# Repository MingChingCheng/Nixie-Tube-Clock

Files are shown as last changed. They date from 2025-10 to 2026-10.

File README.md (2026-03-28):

# Nixie-Tube-Clock

A project of Nixie tube clock.

## Hardware

- Powered by 12V DC charger

## Functions

- Clock with hour and minute
- Temperature
- Humidity
- Time setting mode
- de-poisoning the nixie tube every hour

## Library

List of the libraries used in this project:

- [Adafruit AM2320 sensor library](https://github.com/adafruit/Adafruit_AM2320) (by Adafruit)
- [DS3231](https://github.com/NorthernWidget/DS3231) (by Andrew Wickert)
- [RotaryEncoder](https://github.com/mathertel/RotaryEncoder) (by Matthias Hertel)

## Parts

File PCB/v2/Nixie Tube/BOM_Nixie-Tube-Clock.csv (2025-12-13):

ID | Name | Designator | Footprint | Quantity | Manufacturer Part | Manufacturer | Supplier | Supplier Part | Price | Contributor | link | 3DModel | JLCPCB Part Class | description
1 | 100nF | C1,C2 | C0603 | 2 | CC0603KRX7R9BB104 | YAGEO(国巨) | LCSC | C14663 |  | lcsc | https://item.szlcsc.com/362304.html | C0603_L1.6-W0.8-H0.8 | Basic Part
2 | NH-B2020RGBA-HF | LED1,LED2,LED3,LED4 | LED-ARRAY-SMD_4P-L2.1-W2.1-TL_NH-B2020RGBA | 4 | NH-B2020RGBA-HF | 国星光电 | LCSC | C2874116 |  | LCSC | https://atta.szlcsc.com/upload/public/pdf/source/20210810/F2CC95523506BC87574AF0308E7F77A3.pdf | LED-ARRAY-SMD_4P-L2.1-W2.1-TL_NH-B2020RGBA | Extended Part
3 | 10kΩ | R1,R2,R3,R4 | R2010 | 4 | RC2010FK-0710KL | YAGEO(国巨) | LCSC | C784591 |  | lcsc | https://lcsc.com/eda_search?q=C784591&%26type=1&ref=editor | R2010_L5.0-W2.5-H0.6 | Extended Part
4 | 74HC595 | U5,U6 | SOIC-16_L9.9-W3.9-P1.27-LS6.0-BL | 2 | 74HC595D,118 | Nexperia(安世) | LCSC | C5947 |  | lcsc | http://datasheet.octopart.com/MC14076BDR2G-ON-Semiconductor-datasheet-608107.pdf | SOIC-16_L9.9-W3.9-H1.8-LS6.0-P1.27 |  | 8-Bit Serial-InputSerial or Prallel-Output Shift Register with Latched 3-State Outputs

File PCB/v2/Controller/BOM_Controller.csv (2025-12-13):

ID | Name | Designator | Footprint | Quantity | Manufacturer Part | Manufacturer | Supplier | Supplier Part | Price | Contributor | 3DModel | link | JLCPCB Part Class | image | Resistance(Ohms)
1 | 2.2nF | C5 | C0603 | 1 | 0603B222K500NT | FH(风华) | LCSC | C1604 |  | lcsc | C0603_L1.6-W0.8-H0.8 | https://item.szlcsc.com/362304.html
2 | DC005-2.0MM | DC1 | DC-IN-TH_DC005 | 1 | DC005-2.0MM | SOFNG | LCSC | C111567 |  | lcsc | DC-IN-TH_DC005 | https://item.szlcsc.com/427890.html
3 | HDR-F-2.54_1x2 | H1 | HDR-F-2.54_1X2 | 1 |  |  | LCSC | C49661 |  | LCEDA_Lib | HDR-F-2.54_1x2
4 | HDR-F-2.54_1x5 | H2 | HDR-F-2.54_1X5 | 1 |  |  | LCSC | C50950 |  | LCEDA_Lib | HDR-F-2.54_1x5
5 | KH-2.54FH-1X15P-H8.5 | H4,H5 | HDR-TH_15P-P2.54-V-F | 2 | KH-2.54FH-1X15P-H8.5 | kinghelm(金航标) | LCSC | C2932676 |  | LCSC | HDR-TH_15P-P2.54-V-F | https://lcsc.com/product-detail/Pin-Header-Female-Header_Made-in-China-Made-in-China-Headers-Pins-1-15P-2-54mm_C54102.html | Extended Part
6 | HDR-F-2.54_1x6 | H3,H7 | HDR-F-2.54_1X6 | 2 |  |  | LCSC | C40877 |  | LCEDA_Lib | HDR-F-2.54_1x6
7 | 2.54-1*4P母 | H8 | HDR-TH_4P-P2.54-V-F | 1 | 2.54-1*4P母 | BOOMELE(博穆精密) | LCSC | C2718488 |  | LCSC | HDR-TH_4P-P2.54-F-LI-1X4P | https://item.szlcsc.com/523021.html | Extended Part
8 | HDR-M-2.54_1x15 | J1,J2 | HDR-M-2.54_1X15 | 2 |  |  | LCSC | C124373 |  | LCEDA_Lib | HDR-M-2.54_1x15
9 | HDR-M-2.54_1x5 | J3 | HDR-M-2.54_1X5 | 1 |  |  | LCSC | C358687 |  | LCEDA_Lib | HDR-M-2.54_1x5
10 | HDR-M-2.54_1x2 | J4 | HDR-M-2.54_1X2 | 1 |  |  | LCSC | C124375 |  | LCEDA_Lib | HDR-M-2.54_1x2
11 | 17-21SUYC/TR8 | LED1 | LED0805-R-RD | 1 | KT-0805黄灯 | KENTO | LCSC | C2296 |  | lcsc | LED0805-RD | https://item.szlcsc.com/88042.html | Basic Part
12 | PBSS5350Z,135 | Q2,Q3 | SOT-223-3_L6.5-W3.4-P2.30-LS7.0-BR | 2 | PBSS5350Z,135 | Nexperia(安世) | LCSC | C49692 |  | lcsc | SOT-223-4P_L6.5-W3.5-H1.6-LS7.0-P2.30 | https://item.szlcsc.com/410724.html | Extended Part
13 | 1kΩ | R1,R9,R10 | R0603 | 3 | 0603WAF1001T5E | UNI-ROYAL(厚声) | LCSC | C21190 |  | lcsc | R0603 | https://www.mouser.in/datasheet/2/447/PYu_RT_1_to_0_01_RoHS_L_11-1669912.pdf | Extended Part
14 | 2.2k | R2 | R0603 | 1 | 0603WAF2201T5E | UNI-ROYAL(厚声) | LCSC | C4190 |  | LCEDA_Lib | R0603 | https://www.mouser.in/datasheet/2/447/PYu_RT_1_to_0_01_RoHS_L_11-1669912.pdf
15 | 3.3k | R3 | R0603 | 1 | 0603WAF3301T5E | UNI-ROYAL(厚声) | LCSC | C22978 |  | LCEDA_Lib | R0603 | https://www.mouser.in/datasheet/2/447/PYu_RT_1_to_0_01_RoHS_L_11-1669912.pdf
16 | 33kΩ | R5 | R0603 | 1 | 0603WAF3302T5E | UNI-ROYAL(厚声) | LCSC | C4216 |  | lcsc | R0603 | https://www.mouser.in/datasheet/2/447/PYu_RT_1_to_0_01_RoHS_L_11-1669912.pdf | Extended Part
17 | 10kΩ | R6 | RES-ADJ-TH_3362P | 1 | 3362P-1-103 | BOCHEN(博晨) | LCSC | C118956 |  | LCSC | 3362P | https://lcsc.com/product-detail/Precision-Potentiometer_Made-in-China-3362P-1-105_C20063.html | Extended Part |  | 10K
18 | 330Ω | R13 | R0603 | 1 | 0603WAF3300T5E | UNI-ROYAL(厚声) | LCSC | C23138 |  | LCSC | R0603 | https://www.mouser.in/datasheet/2/447/PYu_RT_1_to_0_01_RoHS_L_11-1669912.pdf | Extended Part
19 | 22kΩ | R8,R15,R17 | R0603 | 3 | 0603WAF2202T5E | UNI-ROYAL(厚声) | LCSC | C31850 |  | lcsc | R0603 | https://www.mouser.in/datasheet/2/447/PYu_RT_1_to_0_01_RoHS_L_11-1669912.pdf | Extended Part
20 | 220Ω | R7,R11,R12,R16 | R0603 | 4 | 0603WAF2200T5E | UNI-ROYAL(厚声) | LCSC | C22962 |  | LCEDA_Lib | R0603 | https://www.mouser.in/datasheet/2/447/PYu_RT_1_to_0_01_RoHS_L_11-1669912.pdf
21 | LM7809T | U1 | TO-220-3_L10.0-W4.5-P2.54-L | 1 | MC7809CTG | onsemi(安森美) | LCSC | C126395 |  | LCSC | TO-220-3_L10.0-W4.5-P2.54-L | https://item.szlcsc.com/233115.html | Extended Part
22 | LM7805T | U2 | TO-220-3_L10.0-W4.5-P2.54-L | 1 | L7805CV-DG | ST(意法半导体) | LCSC | C3795 |  | LCSC | TO-220-3_L10.0-W4.5-P2.54-L | https://item.szlcsc.com/233115.html | Extended Part

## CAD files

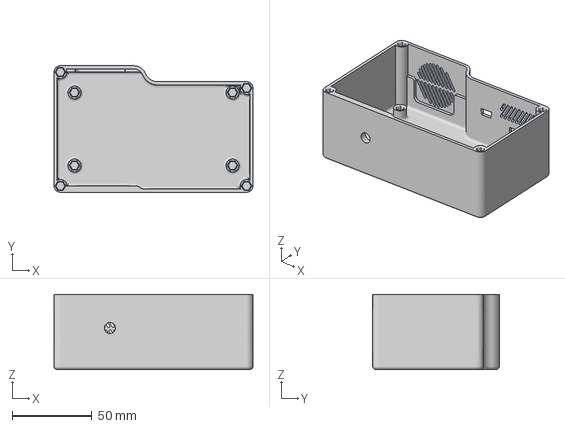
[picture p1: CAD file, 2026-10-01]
3D model/box.3mf
124.7 x 79.3 x 47.0 mm

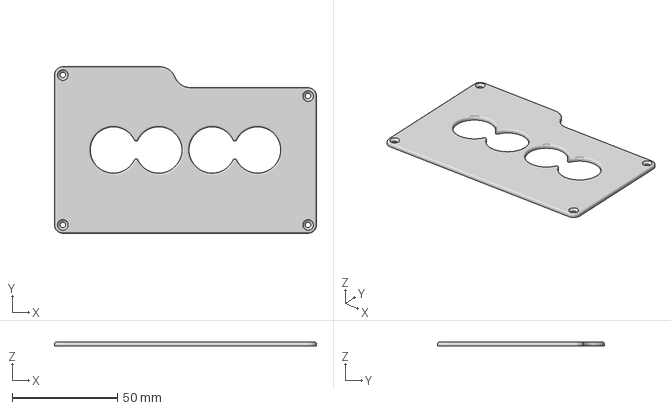
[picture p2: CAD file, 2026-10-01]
3D model/cap.3mf
124.7 x 79.3 x 2.00 mm

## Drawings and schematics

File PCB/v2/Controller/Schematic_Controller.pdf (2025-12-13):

## External Power In

## 9V/5V Voltage Regulation

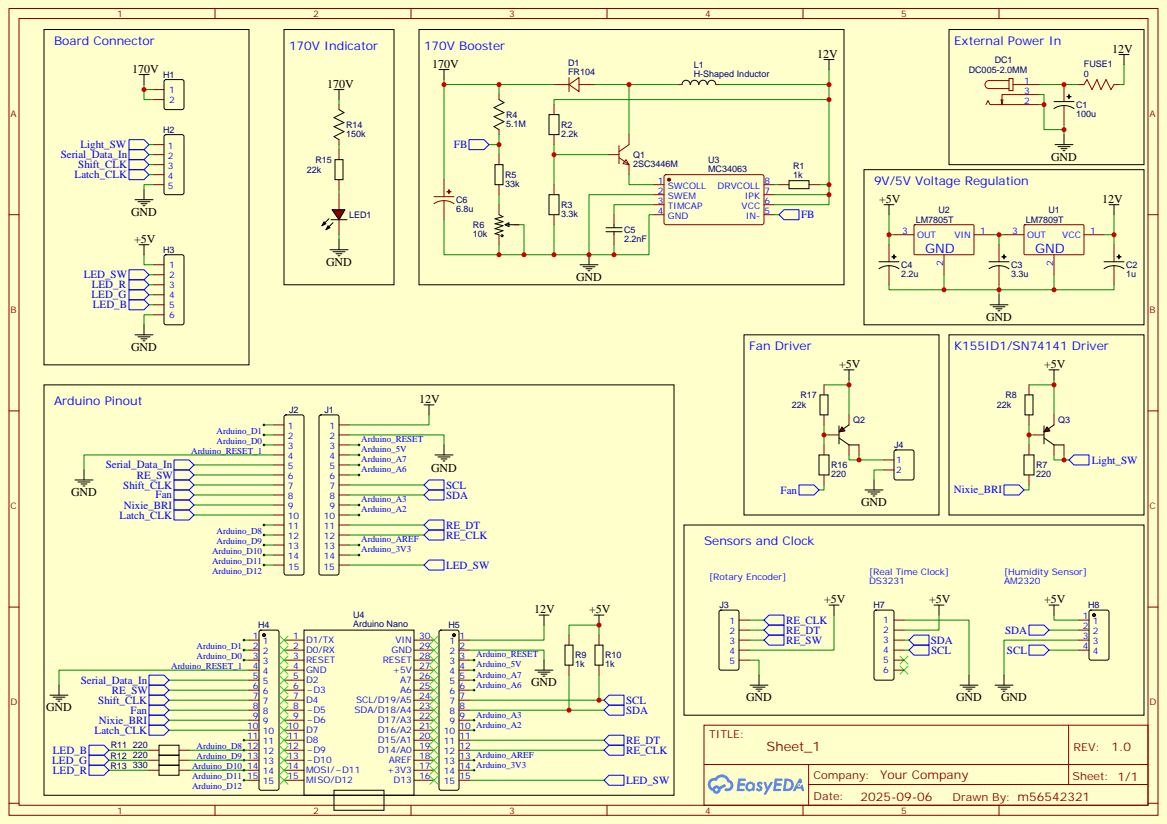
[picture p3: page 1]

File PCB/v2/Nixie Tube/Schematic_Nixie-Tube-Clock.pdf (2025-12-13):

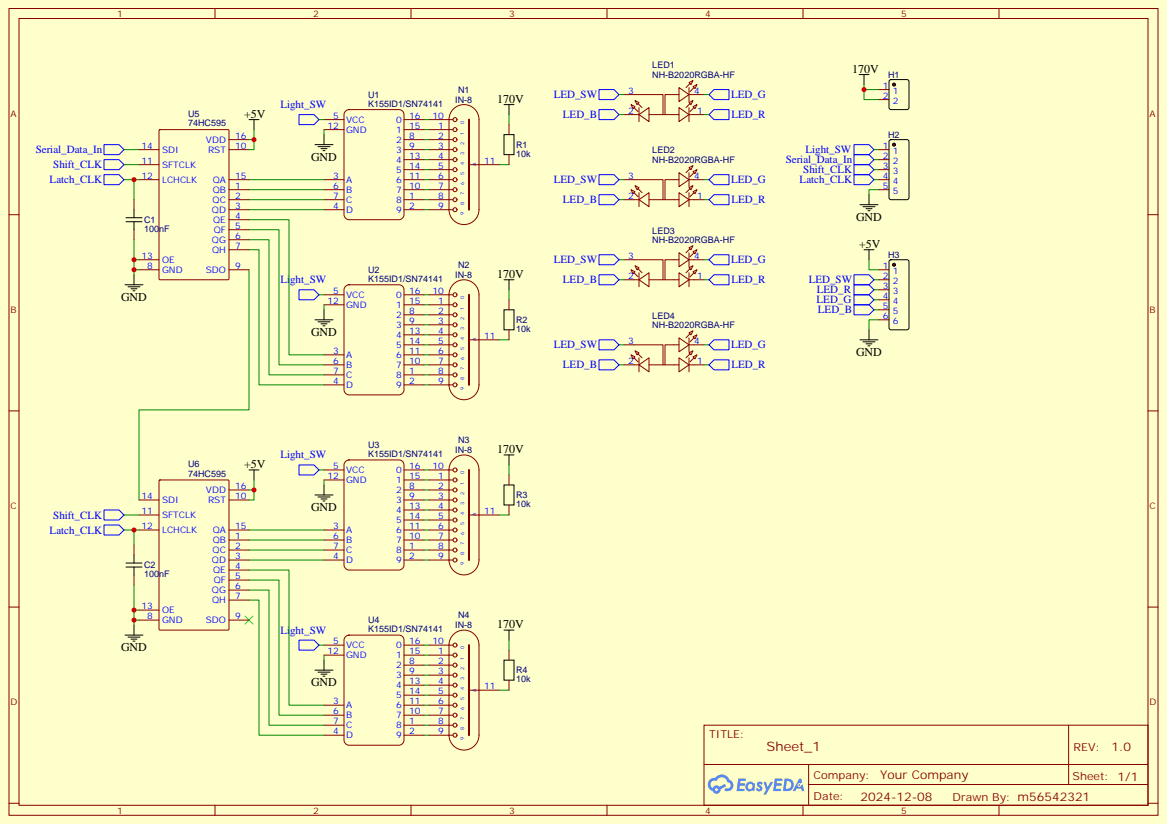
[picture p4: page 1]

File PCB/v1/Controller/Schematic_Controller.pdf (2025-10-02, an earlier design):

## GND

## GND

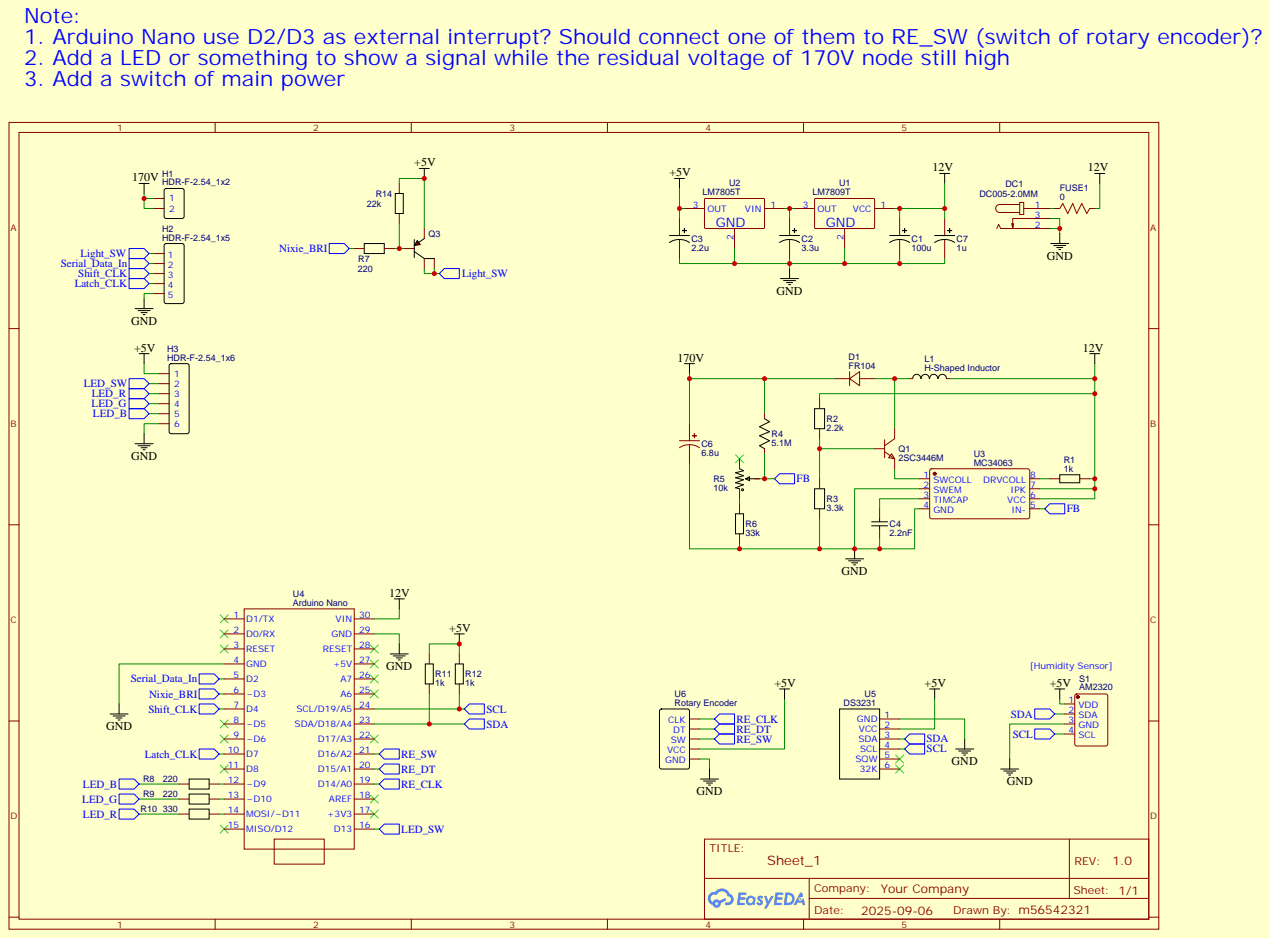
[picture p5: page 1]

Note:
1. Arduino Nano use D2/D3 as external interrupt? Should connect one of them to RE_SW (switch of rotary encoder)?
2. Add a LED or something to show a signal while the residual voltage of 170V node still high
3. Add a switch of main power

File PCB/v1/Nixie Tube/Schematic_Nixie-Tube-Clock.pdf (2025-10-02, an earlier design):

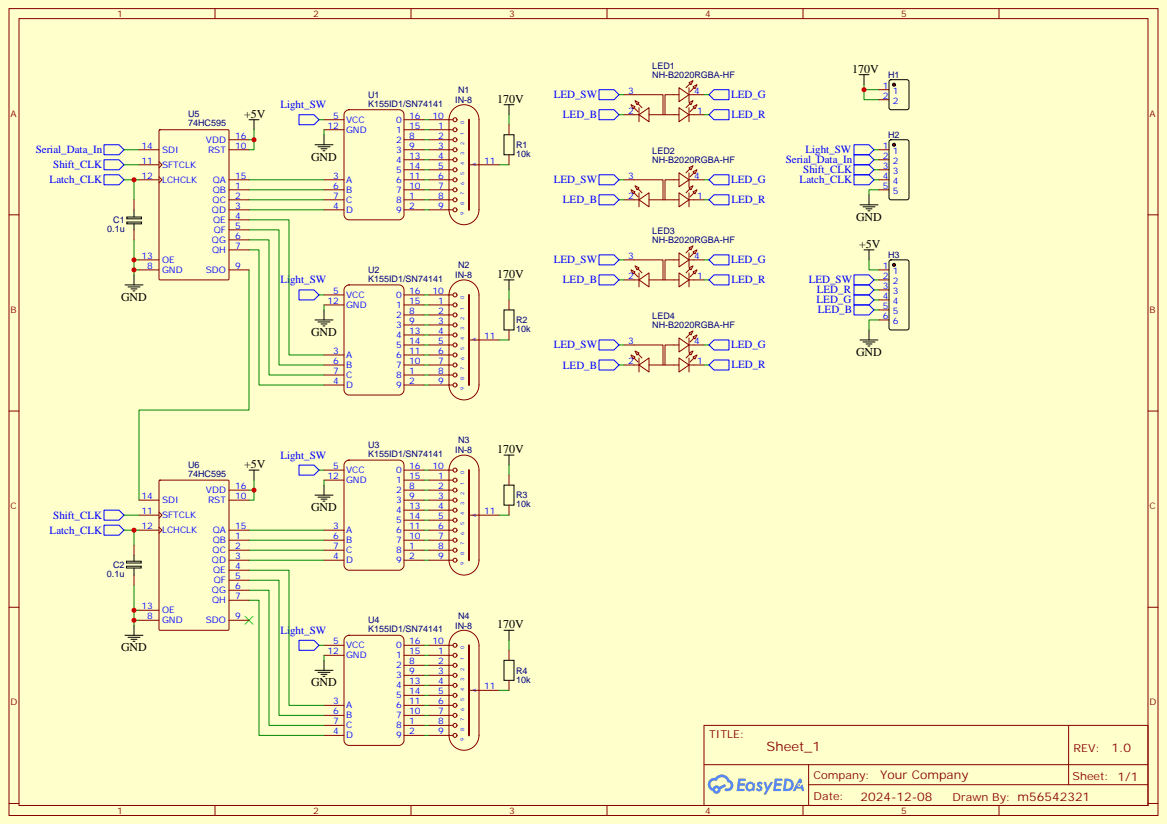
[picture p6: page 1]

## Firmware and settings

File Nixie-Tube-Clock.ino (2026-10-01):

// This code is designed with Arduino Nano
// Display time in 24-hour format on 4-digit Nixie tube

/* Include libraries */
// For Humidity Sensor AM2320
#include <Adafruit_AM2320.h>
#include <Adafruit_Sensor.h>


// For Real Time Clock
#include <DS3231.h>
#include <Wire.h>

// For Rotary Encoder
#include <RotaryEncoder.h>


// Constants
const int NIXIE_BRIGHTNESS = 0;                // brightness level (0-255), 0 is the brightest
const int LED_BRIGHTNESS = 50;                 // brightness level (0-255), 0 is the brightest
const int IDLE_TIME = 30000;                   // 30 seconds
const int COOLING_DURATION = 10000;            // 10 seconds
const float HIGH_TEMPERATURE_THRESHOLD = 40.0; // 40 degrees Celsius
const float TEMP_CALI_AM2320 = -10.0;          // temperature calibration value for AM2320
const float TEMP_CALI_RTC = -10.0;             // temperature calibration value for RTC


/* Define functions */
void blinking_nixie_tube(int duration_ms, int a, int b, int c, int d);
void turn_on_nixie_tube();
void turn_off_nixie_tube();

void show_time();

void show_temp();
float get_temp();

void show_humidity();
float get_humidity();

void display(int a, int b, int c, int d);

void change_mode();
void idle_check();

void poison();
void poison_check();

void set_time();
void set_hour_tens();
void set_hour_ones();
void set_minute_tens();
void set_minute_ones();
int update_digit(int value, int direction, int max_value);

void led_set_color(int red, int green, int blue);

void cooling_check();

/* Define Pins */
// 74HC595
const int latch_pin = 7;
const int clock_pin = 4;
const int data_pin = 2;

// Nixie tube
const int nixie_brightness_pin = 6;

// LED
const int led_brightness_pin = 13;
const int led_red_pin = 11;
const int led_green_pin = 10;
const int led_blue_pin = 9;

// I2C
const int SCL_pin = A5;
const int SDA_pin = A4;

// Rotary encoder
const int rotary_switch_pin = 3;
const int rotary_data_pin = A1;
const int rotary_clock_pin = A0;

// fan
const int fan_pin = 5;


/* Define Objects and global variables of all components */

// Mode
unsigned long idle_start_time;  // record the start time of idle
bool poison_mode_finished = false;

enum CLOCK_MODE {
  SHOW_TIME,             // 0
  SHOW_TEMP,             // 1
  SHOW_HUMIDITY,         // 2
  SETTING_HOUR_TENS,     // 3
  SETTING_HOUR_ONES,     // 4
  SETTING_MINUTE_TENS,   // 5
  SETTING_MINUTE_ONES,   // 6
  SET_TIME,              // 7
  NUMBER_OF_MODES
};
CLOCK_MODE clock_mode = SHOW_TIME;

// Humidity sensor
Adafruit_AM2320 am2320 = Adafruit_AM2320();
float humidity = 0;
float temperature = 0;

// Real Time Clock
DS3231 myRTC;
bool century = false;
bool h12Flag;
bool pmFlag;

int hour = 0;
int new_hour = 0;
int minute = 0;
int new_minute = 0;

// Rotary Encoder
volatile int new_direction = 0;
volatile int last_direction = 0;
volatile unsigned long last_interrupt_time = 0;
RotaryEncoder encoder(rotary_clock_pin, rotary_data_pin, RotaryEncoder::LatchMode::FOUR3);

// Display digits
int displayed_digit_a = 0;
int displayed_digit_b = 0;
int displayed_digit_c = 0;
int displayed_digit_d = 0;

// Fan control
unsigned long fan_start_time; // record the start time of fan cooling

void setup() {

  // Define pin mode
  pinMode(nixie_brightness_pin, OUTPUT);
  pinMode(latch_pin, OUTPUT);
  pinMode(clock_pin, OUTPUT);
  pinMode(data_pin, OUTPUT);
  

  pinMode(led_brightness_pin, OUTPUT);
  pinMode(led_red_pin, OUTPUT);
  pinMode(led_green_pin, OUTPUT);
  pinMode(led_blue_pin, OUTPUT);

  pinMode(fan_pin, OUTPUT);


  // Initial components
  Wire.begin();               // Start the I2C interface
  
  am2320.begin();             // Humidity sensor
  
  clock_mode = SHOW_TIME;     // Real Time Clock
  myRTC.setClockMode(false);  // Real Time Clock mode = false: 24h, mode = true: 12h
  hour = myRTC.getHour(h12Flag, pmFlag);
  minute = myRTC.getMinute();

  // Set fan off at the beginning
  digitalWrite(fan_pin, HIGH);

  // Set nixie tube always on
  digitalWrite(nixie_brightness_pin, LOW);
  // poison mode will be triggered at power on
  poison();

  encoder.setPosition(0);     // Rotary encoder initialize
  attachInterrupt(digitalPinToInterrupt(rotary_switch_pin), change_mode, FALLING);
}

void loop() {

  switch(clock_mode) {

    case SHOW_TIME:
      show_time();
      break;

    case SHOW_TEMP:
      show_temp();
      break;

    case SHOW_HUMIDITY:
      show_humidity();
      break;

    case SETTING_HOUR_TENS:
      set_hour_tens();
      break;

    case SETTING_HOUR_ONES:
      set_hour_ones();
      break;

    case SETTING_MINUTE_TENS:
      set_minute_tens();
      break;

    case SETTING_MINUTE_ONES:
      set_minute_ones();
      break;

    case SET_TIME:
      set_time();
      break;
      
    default:
      // change to default mode
      clock_mode = SHOW_TIME;
      break;

  } // end switch


  poison_check();
  idle_check();
  cooling_check();

  delay(50);

} // end loop


void turn_on_nixie_tube() {
  // turn on the nixie tube by displaying the last digits
  display(displayed_digit_a, displayed_digit_b, displayed_digit_c, displayed_digit_d);
}

void turn_off_nixie_tube() {
  // turn off the nixie tube by sending invalid digits
  display(10, 10, 10, 10); 
}

void blinking_nixie_tube(int duration_ms, int a, int b, int c, int d) {
  // blinking nixie tube every duration

  // get current time
  unsigned long current_time = millis();

  if ( (current_time / duration_ms) % 2 == 0 ) {
    display(a, b, c, d);
  }
  else {
    turn_off_nixie_tube();
  }
}

void show_time() {

  // get time from RTC
  hour = myRTC.getHour(h12Flag, pmFlag);
  minute = myRTC.getMinute();

  // transform to digits
  int hour_tens = (int)(hour / 10);
  int hour_ones = (int)(hour % 10);
  int minute_tens = (int)(minute / 10);
  int minute_ones = (int)(minute % 10);

  // output
  led_set_color(0, 0, 0); // off
  display(hour_tens, hour_ones, minute_tens, minute_ones);
}

void show_temp() {

  temperature = get_temp();

  // transform to digits
  int temperature_int = (int)(temperature * 100);

  int temperature_tens   = (int)(temperature_int / 1000 % 10);
  int temperature_ones   = (int)(temperature_int /  100 % 10);
  int temperature_p_ones = (int)(temperature_int /   10 % 10);
  int temperature_p_tens = (int)(temperature_int /    1 % 10);

  // output
  led_set_color(255, 5, 0); // red orange
  display(temperature_tens, temperature_ones, temperature_p_ones, temperature_p_tens);
}

float get_temp() {
  // get temp from AM2320
  float temp_am2320       = am2320.readTemperature();
  bool  temp_am2320_valid = false;

  // check if the temperature reading from AM2320 is valid
  if (isnan(temp_am2320)) {
    temp_am2320_valid = false;
  }
  else {
    temp_am2320_valid = true;
    temp_am2320 += TEMP_CALI_AM2320;
  }

  // get temp form RTC
  float temp_rtc       = myRTC.getTemperature();
  bool  temp_rtc_valid = false;

  // check if the temperature reading from RTC is valid
  if (temp_rtc == -9999) {
    temp_rtc_valid = false;
  }
  else {
    temp_rtc_valid = true;
    temp_rtc += TEMP_CALI_RTC;
  }

  // return a valid temperature reading
  if (temp_am2320_valid && temp_rtc_valid) {
    // if both are valid, return the higher one
    if (temp_am2320 > temp_rtc) {
      return temp_am2320;
    }
    else {
      return temp_rtc;
    }
  }
  else if (temp_am2320_valid && !temp_rtc_valid) {
    // if only AM2320 is valid, return it
    return temp_am2320;
  }
  else if (!temp_am2320_valid && temp_rtc_valid) {
    // if only RTC is valid, return it
    return temp_rtc;
  }
  else {
    // if both are invalid, return an impossible value
    return 0;
  }
}

void show_humidity() {

  humidity = get_humidity();

  // transform to digits
  int humidity_int = (int)(humidity * 100);

  int humidity_tens   = (int)(humidity_int / 1000 % 10);
  int humidity_ones   = (int)(humidity_int /  100 % 10);
  int humidity_p_ones = (int)(humidity_int /   10 % 10);
  int humidity_p_tens = (int)(humidity_int /    1 % 10);

  // output
  led_set_color(0, 50, 250); // light blue
  display(humidity_tens, humidity_ones, humidity_p_ones, humidity_p_tens);
  
}

float get_humidity() {
  // get humidity from AM2320
  float humidity     = am2320.readHumidity();
  float temp_inside  = am2320.readTemperature();
  float temp_outside = temp_inside + TEMP_CALI_AM2320;

  // calibrate humidity based on temperature
  float vapor_sat_inside  = vapor_pressure_saturation(temp_inside);
  float vapor_sat_outside = vapor_pressure_saturation(temp_outside);

  return humidity * vapor_sat_inside / vapor_sat_outside;
}

float vapor_pressure_saturation(float temp) {
  // https://en.wikipedia.org/wiki/Vapour_pressure_of_water
  // RH = P_w / P_ws * 100%
  float e = 2.718;
  float power = (18.678 - temp / 234.5) * (temp / (257.14 + temp));
  float vapor_pressure_saturation = 0.61121 * pow(e, power);

  return vapor_pressure_saturation;
}

void display(int a, int b, int c, int d) {

  // convert digits to binary format
  byte low_Byte  = (b << 4) | (a);
  byte high_Byte = (d << 4) | (c);

  // store valid displayed digits
  if ( a >=0 && a <=9 &&
       b >=0 && b <=9 &&
       c >=0 && c <=9 &&
       d >=0 && d <=9 ) {
    displayed_digit_a = a;
    displayed_digit_b = b;
    displayed_digit_c = c;
    displayed_digit_d = d;
  }


  // sending data to two 74HC595 ICs
  digitalWrite(latch_pin, LOW);                        // pull down "latch pin" before sending data
  shiftOut(data_pin, clock_pin, MSBFIRST, high_Byte);  // sending data to farther 74HC595
  shiftOut(data_pin, clock_pin, MSBFIRST, low_Byte);   // sending data to closer 74HC595
  digitalWrite(latch_pin, HIGH);                       // pull up "latch pin" after sending data
}

void change_mode() {

  // debounce: ignore if the interrupt occurs within 200ms of the last interrupt
  unsigned long interrupt_time = millis();
  if (interrupt_time - last_interrupt_time < 200) {
    return;
  }
  
  last_interrupt_time = interrupt_time;


  // change to next mode
  // if at the last mode, go back to the first mode
  clock_mode = (CLOCK_MODE)((clock_mode + 1) % NUMBER_OF_MODES);

  // reset idle timer
  if (clock_mode != SHOW_TIME) {
    idle_start_time = millis();
  }

  // initialize when entering setting mode
  if (clock_mode == SETTING_HOUR_TENS) {
    new_hour = hour;
    new_minute = minute;
  }

}

void idle_check() {
  // check if in idle time
  unsigned long current_time = millis();

  // if idle time exceeded, go back to show time mode
  if (clock_mode == SHOW_TEMP ||
      clock_mode == SHOW_HUMIDITY ) {
    if (current_time - idle_start_time >= IDLE_TIME) {
      clock_mode = SHOW_TIME;
    }
  }

  // if in setting mode and idle time exceeded, go to set time mode
  if (clock_mode == SETTING_HOUR_TENS ||
      clock_mode == SETTING_HOUR_ONES ||
      clock_mode == SETTING_MINUTE_TENS ||
      clock_mode == SETTING_MINUTE_ONES ) {
    if (current_time - idle_start_time >= IDLE_TIME) {
      clock_mode = SET_TIME;
    }
  }

}

void poison() {
  
  led_set_color(128, 0, 220); // purple

  // loop through digits 0-9
  int i;
  for ( i=0 ; i<10 ; i++ ) {
    display(i, i, i, i);
    delay(650);
  }

}

void poison_check() {

  // only run poison mode in show time mode
  if (clock_mode == SHOW_TIME) {
  
    // Go to poison mode at every hour
    if ( minute == 0 && poison_mode_finished == false) {
      poison_mode_finished = true;
      poison();
    }

    if ( minute != 0 ) {
      poison_mode_finished = false;
    }
  }
}

void set_time() {
  // set time to RTC
  myRTC.setHour(new_hour);
  myRTC.setMinute(new_minute);

  // retrieve time from RTC
  hour = myRTC.getHour(h12Flag, pmFlag);
  minute = myRTC.getMinute();

  int hour_tens = (int)(hour / 10);
  int hour_ones = (int)(hour % 10);
  int minute_tens = (int)(minute / 10);
  int minute_ones = (int)(minute % 10);

  

  // blink quickly to indicate time is set
  int i = 0;
  for ( i=0 ; i<2 ; i++ ) {
    turn_off_nixie_tube();
    delay(200);
    display(hour_tens, hour_ones, minute_tens, minute_ones);
    delay(200);
  }

  // return to show time mode
  clock_mode = SHOW_TIME;
}

void set_hour_tens() {

  // get old time from RTC
  int hour_tens = (int)(hour / 10);
  int hour_ones = (int)(hour % 10);
  int minute_tens = (int)(minute / 10);
  int minute_ones = (int)(minute % 10);

  int new_hour_tens = (int)(new_hour / 10);
  
  // read rotary encoder
  encoder.tick();
  new_direction = (int)(encoder.getDirection());
  
  // update hour tens based on rotary encoder direction
  if (new_direction != last_direction) {

    // reset idle timer
    idle_start_time = millis();
    
    // update hour tens
    // possible value: 00, 01, 02, ..., 23
    // max value is 2
    new_hour_tens = update_digit(new_hour_tens, new_direction, 2);

    last_direction = new_direction;
  }
  
  // display new time blinking every 500ms
  led_set_color(160, 200, 0);  // yellow green
  blinking_nixie_tube(500, new_hour_tens, hour_ones, minute_tens, minute_ones);
  
  // update new hour
  new_hour = new_hour_tens * 10 + hour_ones;
}

void set_hour_ones() {
  
  // get old time from RTC
  int hour_tens = (int)(hour / 10);
  int hour_ones = (int)(hour % 10);
  int minute_tens = (int)(minute / 10);
  int minute_ones = (int)(minute % 10);

  int new_hour_tens = (int)(new_hour / 10);
  int new_hour_ones = (int)(new_hour % 10);
  
  // read rotary encoder
  encoder.tick();
  new_direction = (int)(encoder.getDirection());
  
  // update hour tens based on rotary encoder direction
  if (new_direction != last_direction) {

    // reset idle timer
    idle_start_time = millis();

    if (new_hour_tens == 2) {
      // possible value: 20, 21, 22, 23
      // max value is 3
      new_hour_ones = update_digit(new_hour_ones, new_direction, 3);
    }
    else {
      // possible value: 00, 01, 02, ..., 09, 10, 11, ..., 19
      // max value is 9
      new_hour_ones = update_digit(new_hour_ones, new_direction, 9);
    }

    last_direction = new_direction;
  }
  
  // display new time blinking every 500ms
  led_set_color(80, 240, 0);  // green yellow
  blinking_nixie_tube(500, new_hour_tens, new_hour_ones, minute_tens, minute_ones);
  
  // update new hour
  new_hour = new_hour_tens * 10 + new_hour_ones;
}

void set_minute_tens() {

  // get old time from RTC
  int hour_tens = (int)(hour / 10);
  int hour_ones = (int)(hour % 10);
  int minute_tens = (int)(minute / 10);
  int minute_ones = (int)(minute % 10);

  int new_hour_tens = (int)(new_hour / 10);
  int new_hour_ones = (int)(new_hour % 10);
  int new_minute_tens = (int)(new_minute / 10);
  
  // read rotary encoder
  encoder.tick();
  new_direction = (int)(encoder.getDirection());
  
  // update hour tens based on rotary encoder direction
  if (new_direction != last_direction) {

    // reset idle timer
    idle_start_time = millis();
    
    // update minute tens
    // possible value: 00, 01, ..., 59
    // max value is 5
    new_minute_tens = update_digit(new_minute_tens, new_direction, 5);
    last_direction = new_direction;
  }
  
  // display new time blinking every 500ms
  led_set_color(0, 240, 80);  // green cyan
  blinking_nixie_tube(500, new_hour_tens, new_hour_ones, new_minute_tens, minute_ones);
  
  // update new hour
  new_minute = new_minute_tens * 10 + minute_ones;
}

void set_minute_ones() {
  
  // get old time from RTC
  int hour_tens = (int)(hour / 10);
  int hour_ones = (int)(hour % 10);
  int minute_tens = (int)(minute / 10);
  int minute_ones = (int)(minute % 10);

  int new_hour_tens = (int)(new_hour / 10);
  int new_hour_ones = (int)(new_hour % 10);
  int new_minute_tens = (int)(new_minute / 10);
  int new_minute_ones = (int)(new_minute % 10);

  // read rotary encoder
  encoder.tick();
  new_direction = (int)(encoder.getDirection());
  
  // update hour tens based on rotary encoder direction
  if (new_direction != last_direction) {

    // reset idle timer
    idle_start_time = millis();

    // update minute tens
    // possible value: 00, 01, ..., 59
    // max value is 9
    new_minute_ones = update_digit(new_minute_ones, new_direction, 9);
    last_direction = new_direction;
  }
  
  // display new time blinking every 500ms
  led_set_color(0, 200, 155);  // blue green
  blinking_nixie_tube(500, new_hour_tens, new_hour_ones, new_minute_tens, new_minute_ones);
  
  // update new minute
  new_minute = new_minute_tens * 10 + new_minute_ones;
}

int update_digit(int value, int direction, int max_value) {
  
  // clockwise (CW): plus
  if (direction == 1) {
    return (value + 1) % (max_value + 1);
  }
  // counterclockwise (CCW): minus
  else if (direction == -1) {
    return (value - 1 + (max_value + 1)) % (max_value + 1);
  }
  // no rotation
  else {
    return value;
  }
}

void led_set_color(int red, int green, int blue) {

  // set on/off
  digitalWrite(led_brightness_pin, HIGH);

  // set color
  // since the LED is controlled by a PNP transistor
  // 0 is highest brightness
  // 255 is lowest brightness
  analogWrite(led_red_pin, (255 - red));
  analogWrite(led_green_pin, (255 - green));
  analogWrite(led_blue_pin, (255 - blue));

}

void cooling_check() {
  // When the temperature is too high,
  // turn on the fan for a constant duration to cool down the system

  float temperature_am2320 = am2320.readTemperature();
  float temperature_rtc = myRTC.getTemperature();
  unsigned long current_time = millis();
  bool fan_on = false;

  if (temperature_am2320 > HIGH_TEMPERATURE_THRESHOLD
      || temperature_rtc > HIGH_TEMPERATURE_THRESHOLD) {

    fan_start_time = current_time; // reset the start time of fan cooling
    fan_on = true;
  }
  else {
    digitalWrite(fan_pin, HIGH); // turn off the fan
  }

  // since the fan is controlled by a PNP transistor
  // LOW is on and HIGH is off
  if (fan_on) {
    if (current_time - fan_start_time < COOLING_DURATION) {
      digitalWrite(fan_pin, LOW); // turn on the fan
    }
    else {
      fan_on = false;
      digitalWrite(fan_pin, HIGH); // turn off the fan
    }
  }
}

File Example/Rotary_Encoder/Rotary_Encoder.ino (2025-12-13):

#include "RotaryEncoder.h"
#include <Arduino.h>


#define PIN_RE_CLK 4
#define PIN_RE_DT 7
#define PIN_RE_SW 2

volatile int pos = 0;
volatile int new_pos = 0;

// Setup a RotaryEncoder with 4 steps per latch for the 2 signal input pins:
// increment for every step is "1"
// counterclockwise(CCW): minus
// clockwise(CW): plus
RotaryEncoder encoder(PIN_RE_CLK, PIN_RE_DT, RotaryEncoder::LatchMode::FOUR3);

// Setup a RotaryEncoder with 2 steps per latch for the 2 signal input pins:
// increment for every step is "2"
// RotaryEncoder encoder(PIN_RE_CLK, PIN_RE_DT, RotaryEncoder::LatchMode::TWO03);

void reset_position()
{
  encoder.setPosition(0);
}

void setup()
{
  Serial.begin(115200);
  while (! Serial)
  {
    delay(10);  // wait until serial port prepared
  };

  Serial.println("SimplePollRotator example for the RotaryEncoder library.");
  Serial.print("Pos: ");
  Serial.println(pos);
  
  // External interrupt for Arduino Uno: D2 and D3
  //                    for Arduino Nano: D2 and D3
  attachInterrupt(digitalPinToInterrupt(PIN_RE_SW), reset_position, FALLING);

} // setup()


// Read the current position of the encoder and print out when changed.
void loop()
{
  encoder.tick();

  new_pos = encoder.getPosition();
  if (pos != new_pos) {
    Serial.print("pos:");
    Serial.print(new_pos);
    Serial.print(" dir:");
    Serial.println((int)(encoder.getDirection()));
    pos = new_pos;
  }

}

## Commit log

2025-09-18 Create gerber
2025-09-18 Create Nixie Tube folder
2025-09-23 Add PCB manufacture data
    [BOM_Nixie-Tube-Clock-Controller_2025-09-14.csv, PickAndPlace_PCB_Controller_2025-09-14.csv]
2025-09-23 Add Example of different sensor/components
2025-09-23 Add library of sensors/components
2025-09-23 Add 1st version of arduino code
2025-10-02 Upload schematics
    [BOM_Nixie-Tube-Clock-Controller_2025-09-14.csv, BOM_Nixie-Tube-Clock_2025-09-14.csv, PickAndPlace_PCB_Controller_2025-09-14.csv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]
2025-12-13 rename PCB files
    [BOM_Controller.csv, BOM_Nixie-Tube-Clock.csv, PickAndPlace_Controller.csv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]
2025-12-13 upload v2 PCB
    [BOM_Controller.csv, BOM_Nixie-Tube-Clock.csv, PickAndPlace_Controller.csv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]
2025-12-14 add led function
2025-12-14 add led color control to different mode
2025-12-14 display digit switch
2025-12-14 control nixie tube on/off
2025-12-14 led set color
2026-01-26 set nixie tube always on
2026-01-26 remove old "turn on nixie tube" function
2026-01-26 Fix bug: hour assigned by minute
    [Nixie-Tube-Clock.ino]
2026-03-09 add LED color control while setting time
2026-03-09 normalize LED brightness
2026-03-28 poison when power on
2026-03-30 modify LED color
2026-03-30 trun-off fan
2026-10-01 Temperature display / fan control
2026-10-01 get temperature from RTC and AM2320
2026-10-01 use "get_temp()" to get temperature
2026-10-01 calculate calibrated humidity
2026-10-01 Upload 3D model
    [box.3mf, cap.3mf]
2026-10-18 Define Temp. Calibration Const
2026-10-18 Add measured power supply info
